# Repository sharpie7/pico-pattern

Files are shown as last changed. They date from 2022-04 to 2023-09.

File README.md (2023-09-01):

# pico-pattern

Pico-pattern is a video pattern generator based on the Raspberry Pi Pico for testing 8-bit era CRT monitors such as the Microvitec Cub. Pico-pattern uses the video generator from [pico-mposite](https://github.com/breakintoprogram/pico-mposite).

The main target of pico-pattern is to generate video with TTL-compatible R,G,B and Composite Sync at 50Hz as used by the BBC Micro.

Pico-pattern offers a range of typical video test patterns including:

- Colour Bars
- Pure White
- Line Grid
- Dot Grid
- Centre Cross Hairs

Pico Pattern

Sorry for the usual difficulties photographing CRTs in the picture!

## Software Build and Deployment

If you want to use the pre-built output then you can just download the file `build/pico-pattern.uf2` and skip to the last paragraph of this section. 

It is recommended to build on a Linux environment. I used Ubuntu under WSL2.

To build yourself follow these instructions:

Install the [Pi Pico C SDK](https://github.com/raspberrypi/pico-sdk) and all the necessary build tools.

Clone this repository to a sibling folder of the SDK. From a commend line cd into the pico-pattern directory and use the following commands (with appropriate change for your system):

```
cd build
cmake -DPICO_SDK_PATH=/path/to/pico-sdk ..
make
```

This should generate a file `build/pico-pattern.uf2`. 

Connect a Pi Pico to the computer while holding down the BOOTSEL button. Copy the `build/pico-pattern.uf2` file to the Pi Pico virtual drive.

## Hardware for Pimoroni Pico Lipo

My version is constructed using a Pimoroni Pico Lipo which creates a battery powered version with a minimum of external components. The schematic is below. In the Pico Lipo the "boot" button doubles as a user button to select the pattern to display.

Originally, I didn't include a 3.3V to 5V level shifter (74AHCT125) because I figured that 3.3V output would be high enough to work with TTL input monitors. This is true, but some monitors (e.g. the Mictovitec Cub) have pull-up resistors on the input going to 5V. **This isn't good for the 3.3V Pi and I fried a few outputs!** In the second version I added a 3.3V to 5V DC module and a 74AHCT125 used as a level shifter.

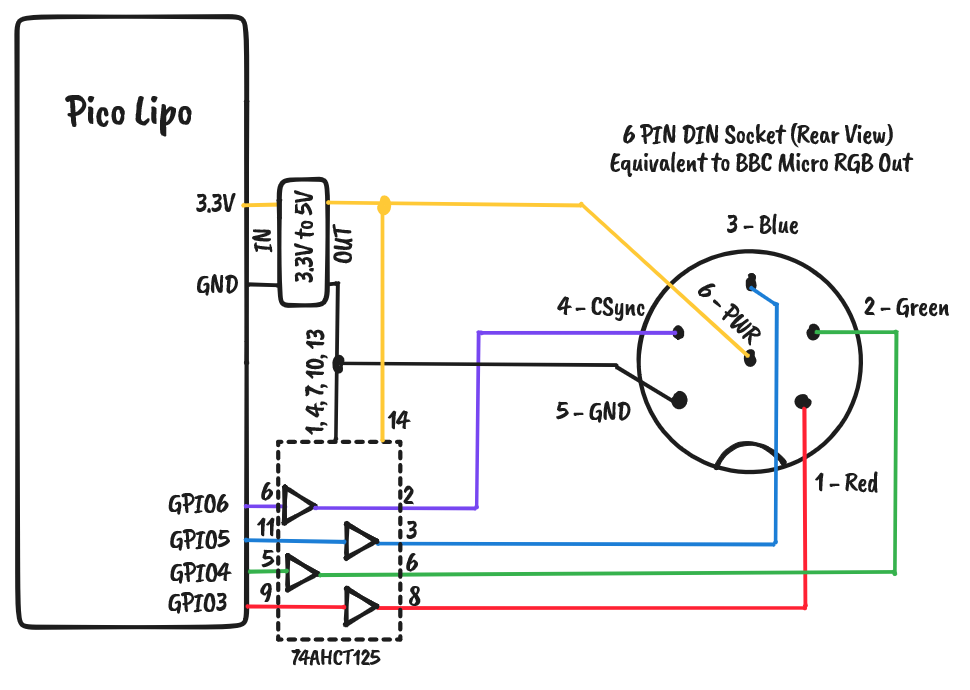
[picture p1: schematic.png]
Pico Lipo Schematic


The second version is constructed on pad-board with a 3D printed case.

## Photos of the second version (with level shifter on daughter board)

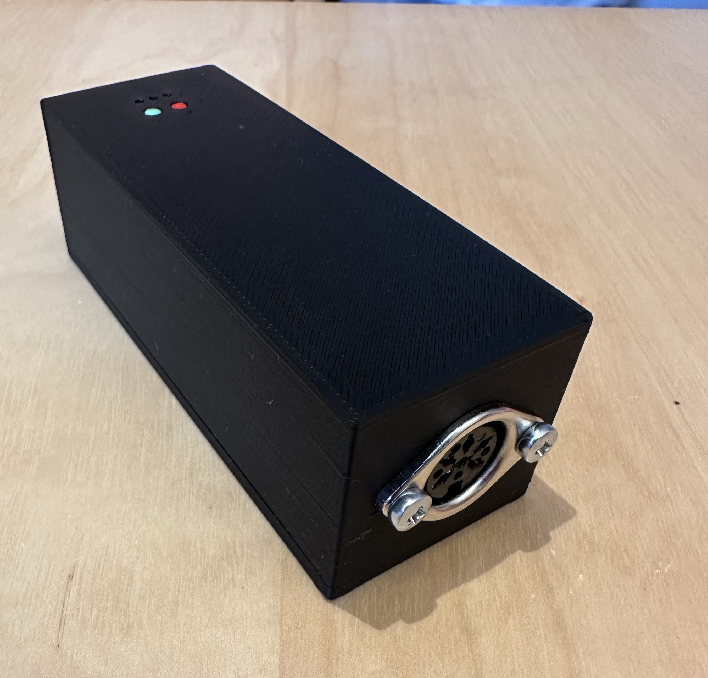
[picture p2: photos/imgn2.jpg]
Pico Pattern V2 Case


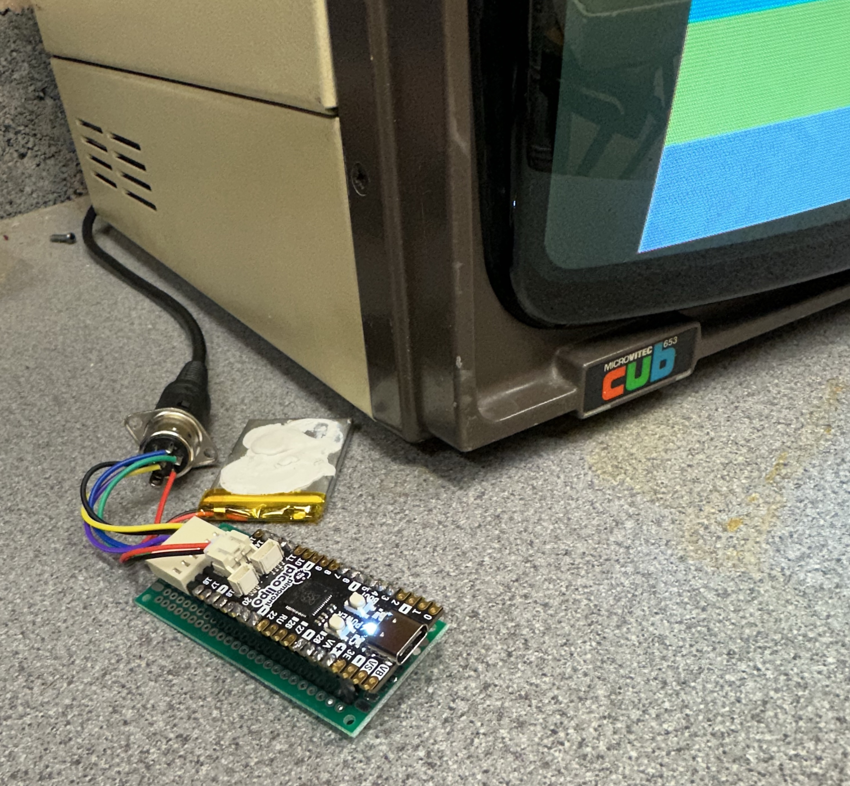
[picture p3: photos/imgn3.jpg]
Pico Pattern V2 Open


## Photos of the first version (without level shifter)

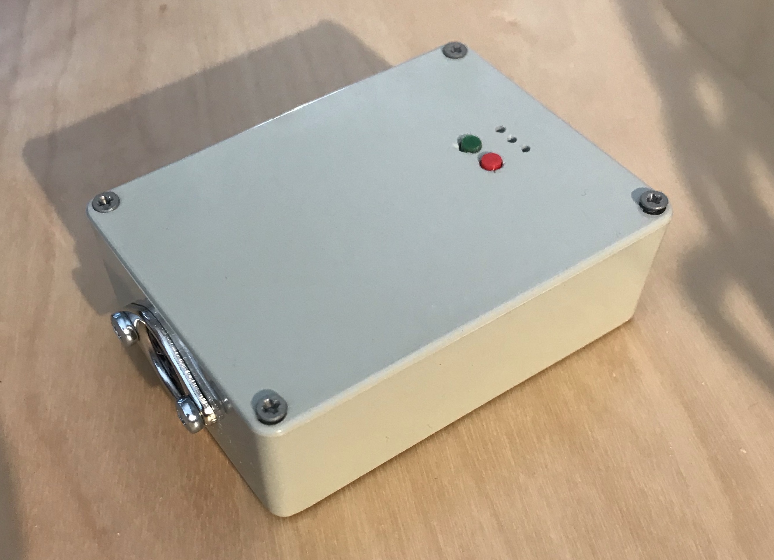
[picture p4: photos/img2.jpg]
Pico Pattern Case


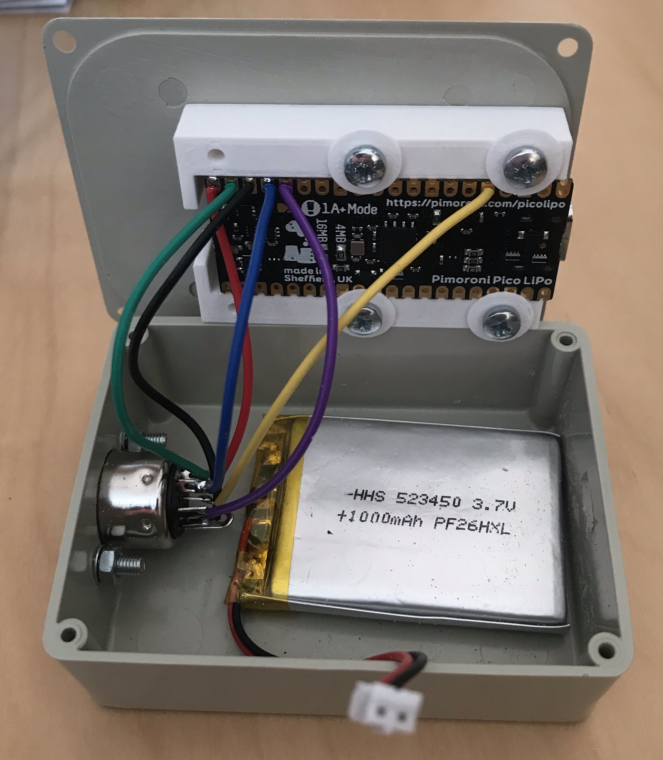
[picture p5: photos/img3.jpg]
Pico Pattern Open


## Hardware for Normal Pi Pico

Connect the DIN socket as shown for the Pico Lipo. If you have a 5V system bus then connect the 5V components to 5V rather than using a DC convertor.

For a normal Pi Pico you will need to add an external user button and change the software to enable a pull up for the user button in the file `main.h`.

You will need to choose a suitable power option. The easiest is just to power from the USB port via an external supply or a USB boost battery. The pattern generator draws about 20mA at 5V or 60mA at 3V so powering from 2 or 3 AA batteries would also be an option. See the Pi Pico Datasheet for information on how to attach an external power supply.

## Use 

Program the Pi Pico as described above. Construct the hardware and connect to a suitable monitor. Power On!

Short presses on the external button will advance through the different patterns. The LED on the Pi Pico will flash the number of the current pattern.

- 1 = Colour Bars Horizontal
- 2 = Colour Bars Vertical
- 3 = Solid Colour Screen
- 4 = Vertical Lines
- 5 = Horizontal Lines
- 6 = Grid
- 7 = Dots
- 8 = Centre Cross Hairs
- 9 = Chess Pattern
- 10 = Border and circle

Holding the external button will choose sub-options in the pattern. Normally this cycles through white, red, green, blue colours.

## Notes

Dean is very disparaging about Pico-mposite, but I think it works really well and demonstrates very nicely the power of the DMA and PIO state machines on the RP2040. Great work Dean! 

Currently the pattern generator only outputs RGB video. It could be adapted to use the existing work in Pico-mposite to output other video formats.

The video output from this device is not interlaced.

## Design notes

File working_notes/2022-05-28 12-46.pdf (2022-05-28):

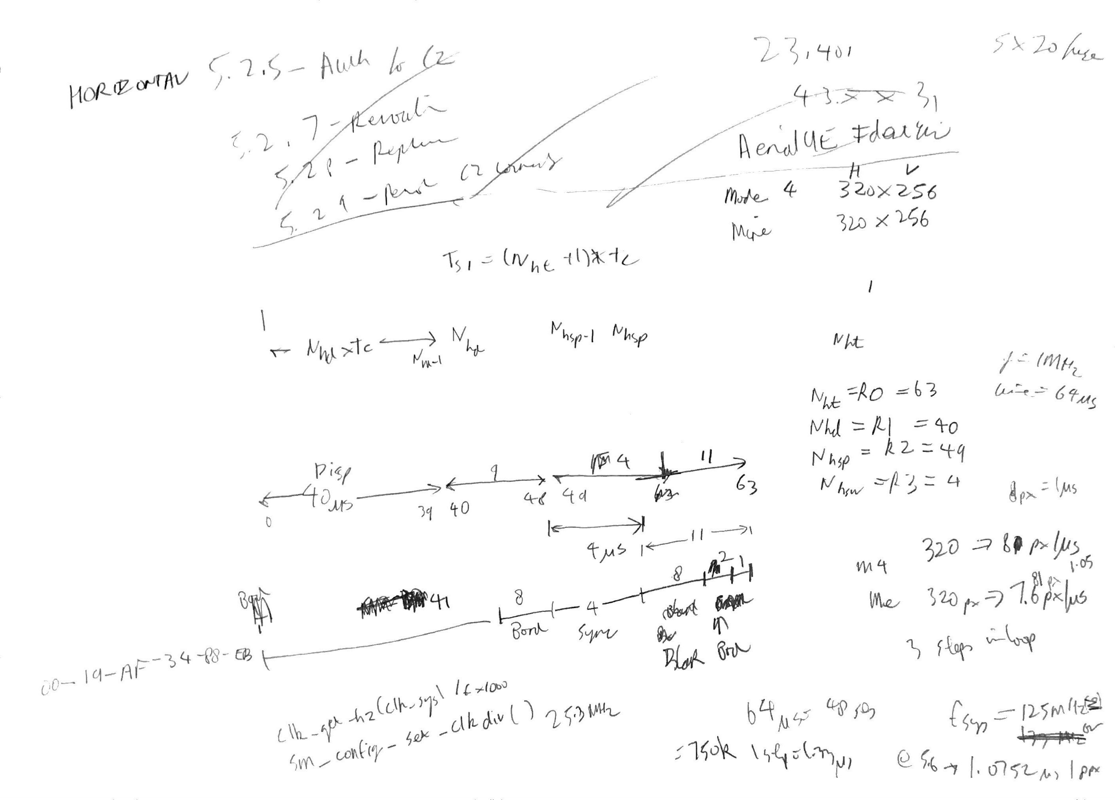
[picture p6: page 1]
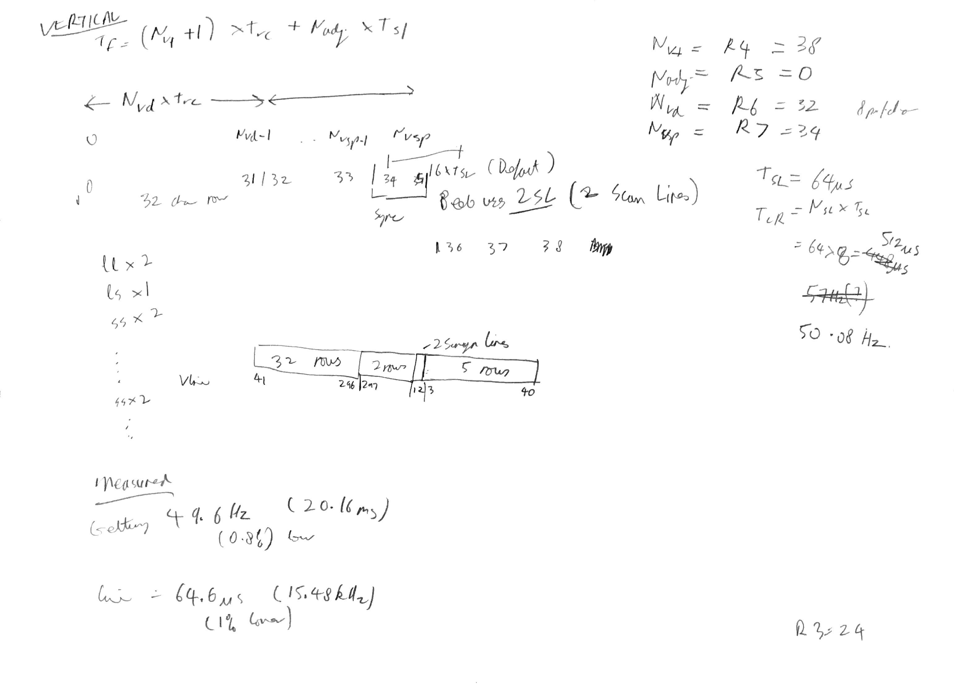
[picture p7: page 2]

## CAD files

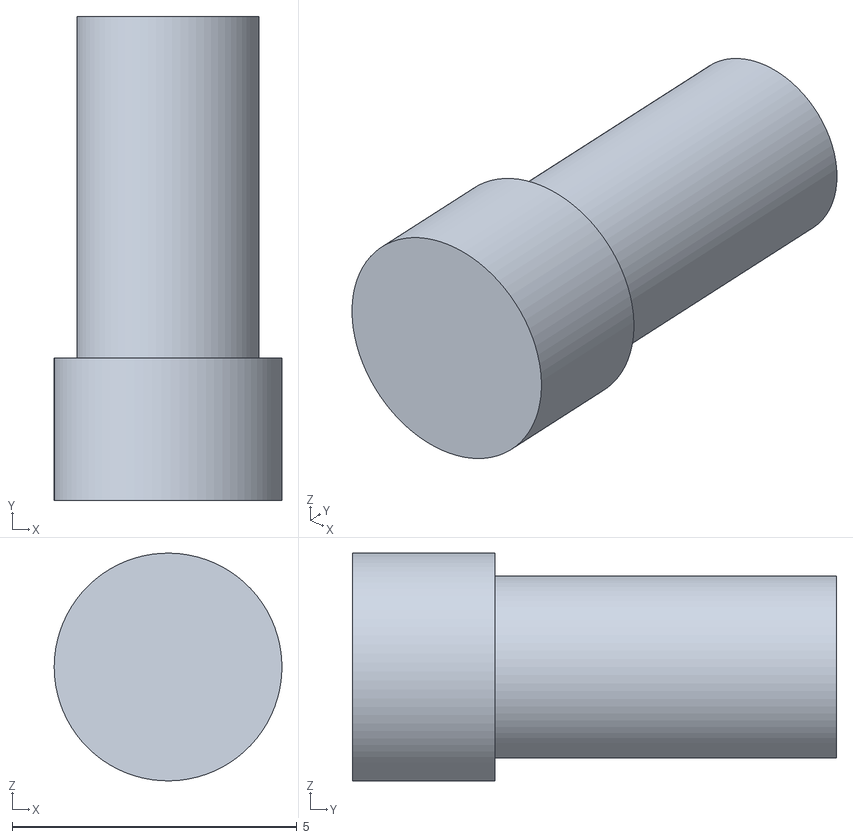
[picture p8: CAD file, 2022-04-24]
3dfiles/pi pico carrier plunger long.stl
4.00 x 8.50 x 4.00

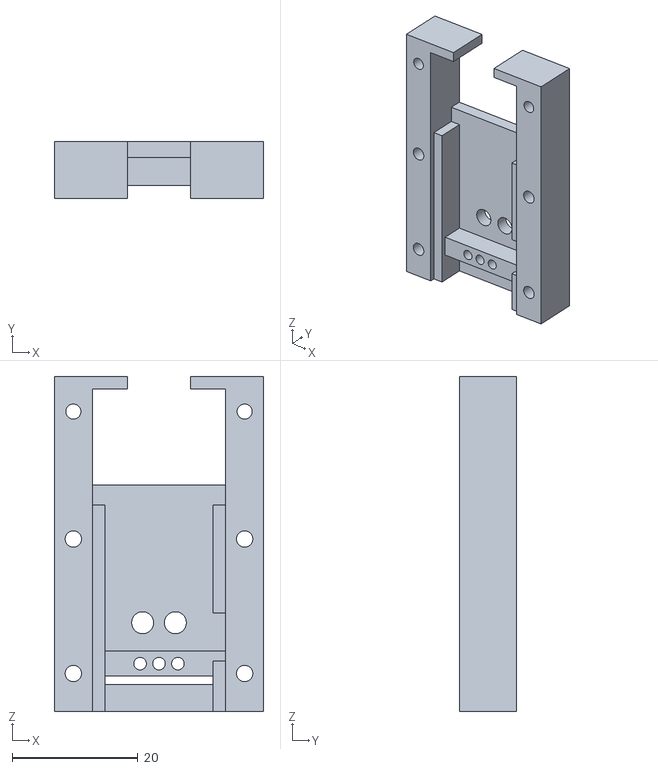
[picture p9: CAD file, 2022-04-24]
3dfiles/pi pico carrier top.stl
33.2 x 9.00 x 53.2

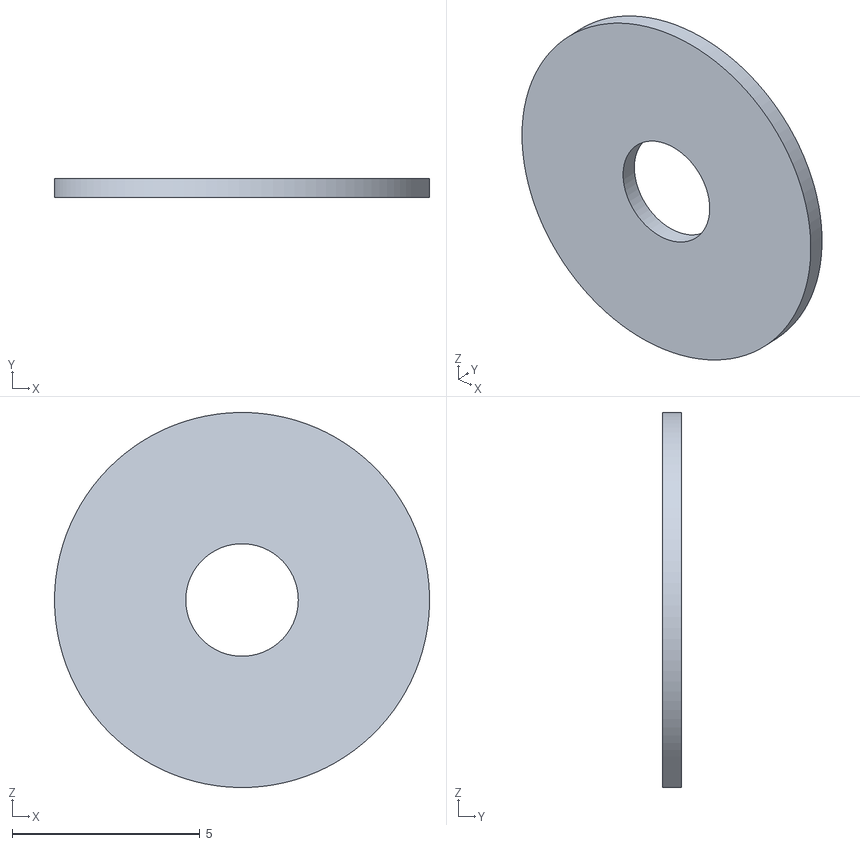
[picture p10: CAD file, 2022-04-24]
3dfiles/pi pico washer.stl
10.00 x 0.5 x 10.00

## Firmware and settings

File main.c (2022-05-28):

//
// Title:	        Pico-mposite Video Output
// Description:		A hacked-together composite video output for the Raspberry Pi Pico
// Author:	        Dean Belfield
// Created:	        02/02/2021
// Last Updated:	01/03/2022
// 
// Modinfo:
// 04/02/2022:      Demos now set the border colour
// 05/02/2022:      Added support for colour
// 20/02/2022:      Added demo_terminal
// 01/03/2022:      Added colour to the demos

#include <stdlib.h>
#include <math.h>

#include "memory.h"
#include "pico/stdlib.h"

#include "hardware/pio.h"
#include "hardware/dma.h"
#include "hardware/irq.h"  
#include "hardware/gpio.h" 

#include "graphics.h"
#include "cvideo.h"

#include "main.h"



// The main loop
//
int main() {
    initialise_cvideo();    // Initialise the composite video stuff
	gpio_init(BUTTON_PIN);
	if (BUTTON_PIN_PULLUP)
		gpio_pull_up(BUTTON_PIN);
	gpio_set_dir(BUTTON_PIN, GPIO_IN);
	gpio_init(LED_PIN);
	gpio_set_dir(LED_PIN, GPIO_OUT);

	const int led_delay = 30;
	const int long_count = 150;
	
    int i =0;
	int sub_c=0;
	int but = 1;
	int but_ready_for_down = true;
	int but_ready_for_up = false;
	int but_up_count = 0;
	int but_down_count = 0;
	int led_count = 0;
    colour_bars_h(0);
	print_string(0,height/16,"github.com/sharpie7/pico-pattern",col_black,col_white);

	while(true) {

		sleep_ms(10);
		led_count ++;
		if (led_count<led_delay*(i+1))
			gpio_put(LED_PIN,(led_count%led_delay)<5);
		else if (led_count <led_delay*(i+1)+60)
			gpio_put(LED_PIN,0);
		else
			led_count = 0;
			
		but = gpio_get(BUTTON_PIN);
		if (!but) {
			if (but_ready_for_down) {
				but_ready_for_down = false;
				but_ready_for_up = true;
			}	
			but_down_count++;
			if (but_down_count>long_count) {
				sub_c ++;
				but_down_count=0;
				but_ready_for_up = false;
				draw_pattern(i, sub_c);
			}
		} else {
			if (but_ready_for_up) {
				sub_c=0;
				but_up_count = 0;
				i=(i+1)%10;
				draw_pattern(i, sub_c);
			}
			if (but_up_count < 2) 
				but_up_count ++;
			else
				but_ready_for_down = true;
			but_ready_for_up = false;
			but_down_count = 0;
		}
	}
}

void draw_pattern(int i, int sub_c) {
	switch (i) {
		case 0: colour_bars_h(sub_c);
		break;
		case 1: colour_bars_v(sub_c);
		break;
		case 2: full_colour(sub_c);
		break;
		case 3: grid(true,false,sub_c);
		break;
		case 4: grid(false,true,sub_c);
		break;
		case 5: grid(true,true,sub_c);
		break;
		case 6: dots(sub_c);
		break;
		case 7: cross(sub_c);
		break;
		case 8: chess(sub_c);
		break;
		default:
			test_circle();
	}
}

unsigned char sub_c_2_col(int sub_c) {
	unsigned char c[4] = {col_white, col_red, col_green, col_blue};
	return c[sub_c%4];
}

void grid(bool draw_h, bool draw_v,int sub_c) {
	set_border(col_black);
	cls(col_black);
	unsigned char c = sub_c_2_col(sub_c);
	const int d=(width+10)/12;
	if (draw_v)
		for (int x = 0; x<8; x++) {
			draw_line(width/2+d*x,0,width/2+d*x,height-1,c);
			if (x>0)
				draw_line(width/2-d*x,0,width/2-d*x,height-1,c);
		}
	if (draw_h)
		for (int y = 0; y<6; y++) {
			draw_line(0,height/2+d*y,width-1,height/2+d*y,c);
			if (y>0)
				draw_line(0,height/2-d*y,width-1,height/2-d*y,c);
		}
	draw_circle(width/2,height/2,d/2,c,0);
}

void dots(int sub_c) {
	set_border(col_black);
	cls(col_black);
	const int d=(width+10)/12;
	for (int x = -7; x<8; x++)
		for (int y = -5; y<6; y++)
			plot(width/2+x*d,height/2+y*d,sub_c_2_col(sub_c));
}

void cross(int sub_c) {
	set_border(col_black);
	cls(col_black);
	draw_line(0,height/2,width-1,height/2,sub_c_2_col(sub_c));
	draw_line(width/2,0,width/2,height-1,sub_c_2_col(sub_c));
}

void full_colour(int sub_c) {
	set_border(sub_c_2_col(sub_c));
	cls(sub_c_2_col(sub_c));
}

void colour_bars_v(int sub_c) {
	const int rectw = width/8;
	const unsigned char c[8] = {col_white, col_yellow, col_cyan, col_green, col_magenta, col_red, col_blue, col_black};
	set_border(col_black);
	cls(col_black);
	for (int i =0; i<8 ; i++) {
		draw_rect(i*rectw,0,i*rectw+rectw-1,height,c[(sub_c%2)?7-i:i],1);
	}
}

void colour_bars_h(int sub_c) {
	const int recth = height/8;
	const unsigned char c[8] = {col_white, col_yellow, col_cyan, col_green, col_magenta, col_red, col_blue, col_black};
	set_border(col_black);
	cls(col_black);
	for (int i =0; i<8 ; i++) {
		draw_rect(0,i*recth,width, i*recth+recth-1,c[(sub_c%2)?i:7-i],1);
	}
}

void chess(int sub_c) {
	set_border(col_black);
	cls(col_black);
	const int n=5;
	const int d=(width+10)/(2*n);
	for (int x = -n; x<n; x++) 
		for (int y = -n; y<n; y++)
			if ((x+y+((sub_c/4)%2))%2)
				draw_rect(width/2+x*d,height/2+y*d,width/2+x*d+d-1,height/2+y*d+d-1,sub_c_2_col(sub_c),1);
}

void test_circle() {
    set_border(col_black);
	cls(col_green);

	draw_line(0,0,width-1,0,col_white);
	draw_line(width-1,0,width-1,height-1,col_white);
	draw_line(width-1,height-1,0,height-1,col_white);
	draw_line(0,height-1,0,0,col_white);
	draw_circle(width/2,height/2,height/2-10,col_black,0);
	

}

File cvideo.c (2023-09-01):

//
// Title:	        Pico-mposite Video Output
// Description:		The composite video stuff
// Author:	        Dean Belfield
// Created:	        26/01/2021
// Last Updated:	25/02/2022
//
// Modinfo:
// 15/02/2021:      Border buffers now have horizontal sync pulse set correctly
//                  Decreased RAM usage by updating the image buffer scanline on the fly during the horizontal interrupt
//					Fixed logic error in cvideo_dma_handler; initial memcpy done twice
// 31/01/2022:      Refactored to use less memory
//					Split the video generation into two state machines; sync and data
// 01/02/2022:      Added a handful of graphics primitives
// 02/02/2022:      Split main loop out into main.c
// 04/02/2022:      Added set_border
// 05/02/2022:      Added support for colour, fixed bug in video generation
// 20/02/2022:      Bitmap is now dynamically allocated; added two higher resolution video modes
// 25/02/2022:      Lengthened HSYNC to 12us

#include <stdlib.h>

#include "memory.h"
#include "pico/stdlib.h"

#include "hardware/pio.h"
#include "hardware/dma.h"
#include "hardware/irq.h"   

#include "charset.h"            // The character set
#include "cvideo.h"
#include "graphics.h"
#include "cvideo_sync.pio.h"    // The assembled PIO code
#include "cvideo_data.pio.h"

PIO pio_0;                      // The PIO that this uses
uint offset_0;                  // Program offsets
uint offset_1;

uint dma_channel_0;             // DMA channel for transferring sync data to PIO
uint dma_channel_1;             // DMA channel for transferring pixel data data to PIO
uint vline;                     // Current PAL(ish) video line being processed
uint bline;                     // Line in the bitmap to fetch

uint vblank_count;              // Vblank counter

unsigned char * bitmap;         // Bitmap buffer

int width = 320;                // Bitmap dimensions             
int height = 256;

/*
 * The sync tables consist of 32 entries, each one corresponding to a 2us slice of the 64us
 * horizontal sync. The value 0x00 is reserved as a control byte for the horizontal sync;
 * cvideo_sync will not write to the GPIO for that block of 0x00's.
 * 
 * All sync pulses are active low
 */


// Horizontal sync with gap for pixel data
//
unsigned short hsync[32] = {
    HSLO, HSLO, HSHI, HSHI, HSHI, HSHI, BORD, 0x00, 0x00, 0x00, 0x00, 0x00, 0x00, 0x00, 0x00, 0x00,
    0x00, 0x00, 0x00, 0x00, 0x00, 0x00, 0x00, 0x00, 0x00, 0x00, 0x00, 0x00, BORD, BORD, BORD, BORD,
};

// Horizontal sync for top and bottom borders
//
unsigned short border[32] = {
    HSLO, HSLO, HSHI, HSHI, HSHI, HSHI, BORD, BORD, BORD, BORD, BORD, BORD, BORD, BORD, BORD, BORD, 
    BORD, BORD, BORD, BORD, BORD, BORD, BORD, BORD, BORD, BORD, BORD, BORD, BORD, BORD, BORD, BORD, 
};

#if opt_colour!=2
// Vertical sync (long/long)
//
unsigned short vsync_ll[32] = {
    VSLO, VSLO, VSLO, VSLO, VSLO, VSLO, VSLO, VSLO, VSLO, VSLO, VSLO, VSLO, VSLO, VSLO, VSLO, VSHI, // Long sync pulse
    VSLO, VSLO, VSLO, VSLO, VSLO, VSLO, VSLO, VSLO, VSLO, VSLO, VSLO, VSLO, VSLO, VSLO, VSLO, VSHI, // Long sync pulse
};

// Vertical sync (short/short)
//
unsigned short vsync_ss[32] = {
    VSLO, VSHI, VSHI, VSHI, VSHI, VSHI, VSHI, VSHI, VSHI, VSHI, VSHI, VSHI, VSHI, VSHI, VSHI, VSHI, // Short sync pulse
    VSLO, VSHI, VSHI, VSHI, VSHI, VSHI, VSHI, VSHI, VSHI, VSHI, VSHI, VSHI, VSHI, VSHI, VSHI, VSHI, // Short sync pulse
};

// Vertical sync (long/short)
//
unsigned short vsync_ls[32] = {
    VSLO, VSLO, VSLO, VSLO, VSLO, VSLO, VSLO, VSLO, VSLO, VSLO, VSLO, VSLO, VSLO, VSLO, VSLO, VSHI, // Long sync pulse
    VSLO, VSHI, VSHI, VSHI, VSHI, VSHI, VSHI, VSHI, VSHI, VSHI, VSHI, VSHI, VSHI, VSHI, VSHI, VSHI, // Short sync pulse
};

#else
	
unsigned short vsync_ll[32] = {
    VSLO, VSLO, VSLO, VSLO, VSLO, VSLO, VSLO, VSLO, VSLO, VSLO, VSLO, VSLO, VSLO, VSLO, VSLO, VSLO, 
    VSLO, VSLO, VSLO, VSLO, VSLO, VSLO, VSLO, VSLO, VSLO, VSLO, VSLO, VSLO, VSLO, VSLO, VSLO, VSLO,
};

#define vsync_ss border
#define vsync_ls border


#endif


/*
 * The main routine sets up the whole shebang
 */
int initialise_cvideo(void) { 
	for(short i = 0; i < gpio_count; i++) {
		gpio_init( i + gpio_base);
		gpio_set_dir( i + gpio_base, GPIO_OUT);
	}

    pio_0 = pio0;	                    // Assign the PIO

    // Load up the PIO programs
    //
    offset_0 = pio_add_program(pio_0, &cvideo_sync_program);
    offset_1 = pio_add_program(pio_0, &cvideo_data_program);

    dma_channel_0 = dma_claim_unused_channel(true);	// Claim a DMA channel for the sync
    dma_channel_1 = dma_claim_unused_channel(true);	// And one for the pixel data

    vline = 1;          // Initialise the video scan line counter to 1
    bline = 0;	        // And the index into the bitmap pixel buffer to 0
    vblank_count = 0;   // And the vblank counter

	// Initialise the first PIO (video sync)
	//
    pio_sm_set_enabled(pio_0, sm_sync, false);	// Disable the PIO state machine
    pio_sm_clear_fifos(pio_0, sm_sync);			// Clear the PIO FIFO buffers
    cvideo_sync_initialise_pio(					// Initialise the PIO (function in cvideo.pio)
		pio_0,									// The PIO to attach this state machine to
		sm_sync,								// The state machine number
		offset_0,								// And offset
		gpio_base,								// Start pin in the GPIO
		gpio_count,								// Number of pins
		piofreq_0								// State machine clock frequency
	);	
    cvideo_configure_pio_dma(					// Configure the DMA for Sync
        pio_0,									// The PIO to attach this DMA to
        sm_sync,								// The state machine number
        dma_channel_0,							// The DMA channel
        DMA_SIZE_16,                            // Size of each transfer
        32,										// Number of transfers to make
        cvideo_dma_handler						// The DMA handler
    );
    pio_sm_set_enabled(pio_0, sm_sync, true);	// Enable the PIO state machine

    bitmap = malloc(width * height);            // Allocate the bitmap memory

	// Initialise the second PIO (pixel data)
	//
    cvideo_data_initialise_pio(					
		pio_0,
		sm_data,
		offset_1,
		gpio_base,
		gpio_data_count,
		piofreq_1_320
	);

    // Initialise the DMA for data (ie pixels)
    //
    cvideo_configure_pio_dma(
        pio_0,	
        sm_data,
        dma_channel_1,							// On DMA channel 1
        DMA_SIZE_8,                             // Size of each transfer
        width,									// The bitmap width - number of transfers to make
        NULL									// But there is no DMA interrupt for the pixel data
    ); 
    pio_sm_set_enabled(pio_0, sm_data, true);	// Enable the PIO state machine

    irq_set_exclusive_handler(					// Set up the PIO IRQ handler
		PIO0_IRQ_0,								// The IRQ #
		cvideo_pio_handler						// And handler routine
	); 
    pio0_hw->inte0 = PIO_IRQ0_INTE_SM0_BITS;	// Just for IRQ 0 (triggered by irq set 0 in PIO)
    irq_set_enabled(PIO0_IRQ_0, true);			// Enable it
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

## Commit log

2022-04-27 Fix circuit
2022-05-28 text on power on only
